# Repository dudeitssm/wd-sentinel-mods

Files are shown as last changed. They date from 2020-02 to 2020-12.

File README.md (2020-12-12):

WD Sentinel NAS related mods and custom PCBs
---

Contains custom PCBs, mods, etc, relating to the WD Sentinel DX4000 NAS.

How to get started?

1. Download the KiCAD archives (zip files)
2. Unarchive the zips
3. Use OSHPark or any fabhouse to print out the ".kicad_pcb" PCBs

Shoot me an email or open an issue if you have questions: moltensolderlabs AT pm.me

Everything licensed as CC0. Do whatever you want with these files.

Enjoy! Other projects are available on my site: moltensolderlabs.com

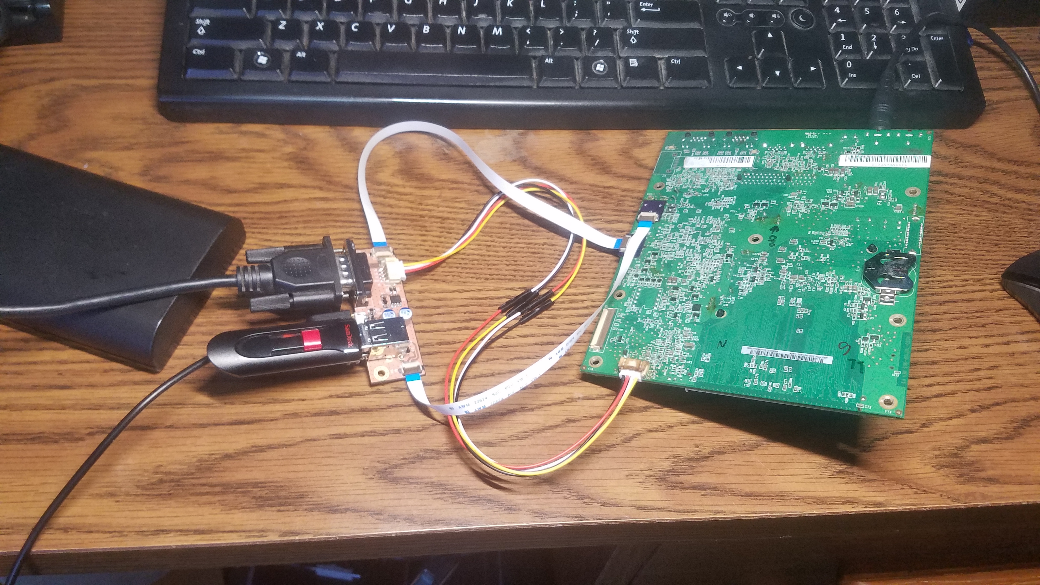
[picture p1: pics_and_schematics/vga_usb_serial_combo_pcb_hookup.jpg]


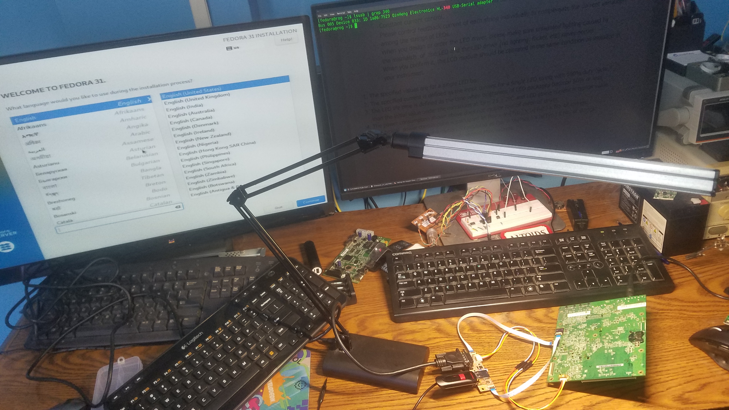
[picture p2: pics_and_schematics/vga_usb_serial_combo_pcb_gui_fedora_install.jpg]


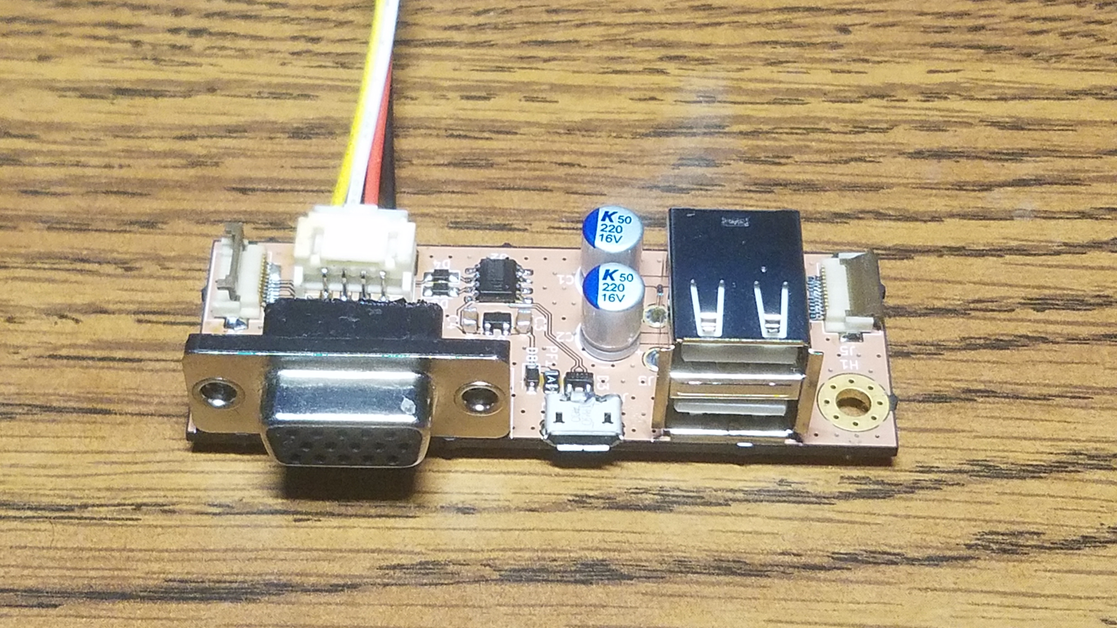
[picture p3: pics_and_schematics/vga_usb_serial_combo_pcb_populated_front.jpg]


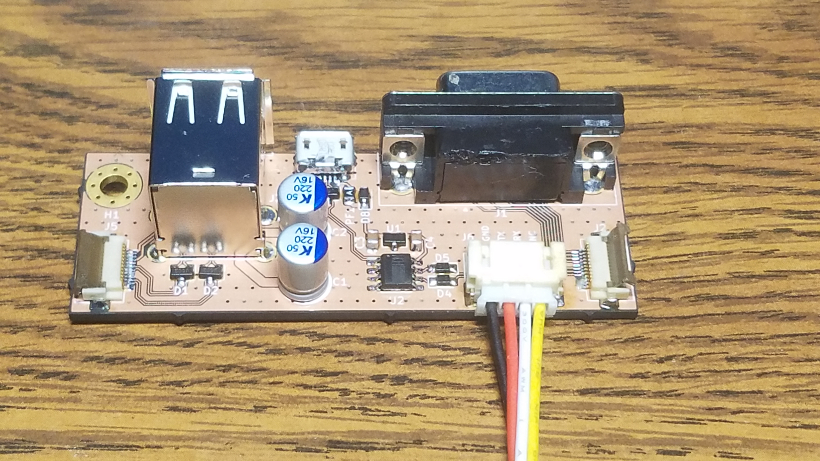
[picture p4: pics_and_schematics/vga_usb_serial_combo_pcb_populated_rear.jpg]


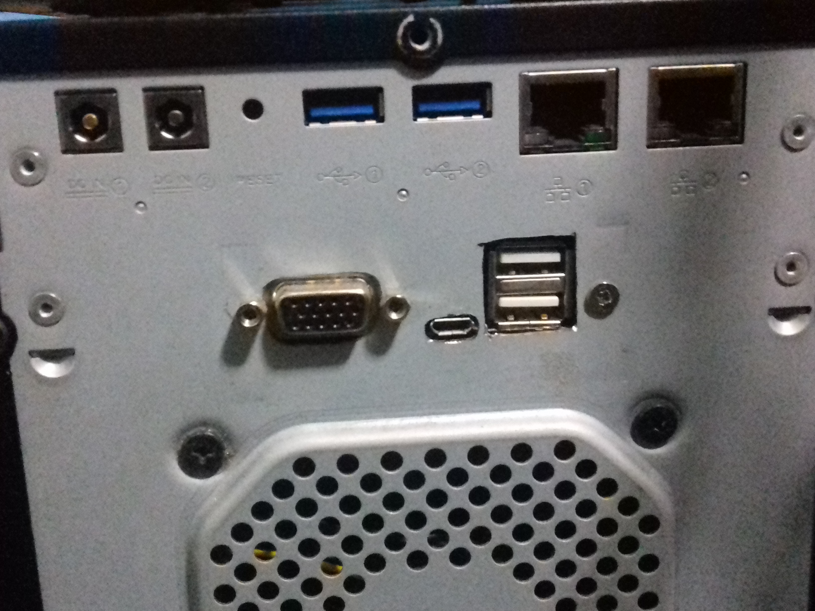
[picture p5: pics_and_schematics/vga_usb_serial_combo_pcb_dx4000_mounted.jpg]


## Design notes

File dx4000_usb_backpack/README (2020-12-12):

* This backpack is meant to be soldered onto the J15 header, a dual-USB header.
--> very lightly coat the pads with solder paste or solder, then use a hot air gun to solder.
--> a 12 pin FFC cable plugs into the combo PCB's USB header.
--> WARNING: you MUST use the same-side-up facing FFC cable, or you can short the USB.

* Note that F1 and F3 next to the J15 header are unpopulated. USB will not work without these.
--> you should solder 1 to 1.5A polyfuses; size, SMD 1210, 3.2mm x 2.5mm.

===

If ya liked this project, or have an improvement in mind, send me an email at moltensolderlabs AT pm.me

Cherish your little Sentinel! I love mine <3

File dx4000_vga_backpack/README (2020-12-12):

* This backpack is meant to be soldered onto the J3 header, a VGA header.
--> very lightly coat the pads with solder paste or solder, then use a hot air gun to solder.
--> a 12 pin FFC cable plugs into the combo PCB's VGA header.
--> WARNING: you MUST use the same-side-up facing FFC cable, or you can short the VGA.

===

If ya liked this project, or have an improvement in mind, send me an email at moltensolderlabs AT pm.me

Cherish your little Sentinel! I love mine <3

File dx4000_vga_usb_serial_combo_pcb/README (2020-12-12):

* This is a combo PCB that provides serial console, VGA, and dual USB2.0 support to the WD Sentinel DX4000.
--> a 12 pin FFC cable plugs into the USB backpack PCB.
--> a 12 pin FFC cable plugs into the VGA packpack PCB.
--> a 4 pin JST cable plugs into the serial port, located at the front of the DX4000 motherboard.
--> WARNING: you MUST use the same-side-up facing FFC cable, or you can short the USB or VGA.

===

If ya liked this project, or have an improvement in mind, send me an email at moltensolderlabs AT pm.me

Cherish your little Sentinel! I love mine <3

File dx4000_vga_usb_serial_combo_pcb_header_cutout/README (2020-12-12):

1. Print out the PDF file with *scaling DISABLED*
2. See that horizontal line above the cutouts? Get a ruler and see it measures exactly, or very close (+/-1mm) to 7cm
3. Tape the cutout to your DX4000 where the Windows Server COA sticker is located.
4. Disconnect and take out the motherboard and all HDDs.
5. Use a center punch to make dents where holes will be drilled.
6. Use a dremel/drill/file/whatever to cut out slots for the VGA, USB, and microUSB ports, and drill holes where indicated.
7. Solder and install the VGA, serial, USB combo PCB.
8. ??
9. Profit. You now have a DX4200, basically.

===

If ya liked this project, or have an improvement in mind, send me an email at moltensolderlabs AT pm.me

Cherish your little Sentinel! I love mine <3

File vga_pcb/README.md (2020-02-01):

A very small, and therefore, very cheap VGA PCB for the Sentinel DX4000.

It needs a small daughterboard that has to be soldered, using hot air gun, onto the 12 pin VGA header on the Sentinel's motherboard.

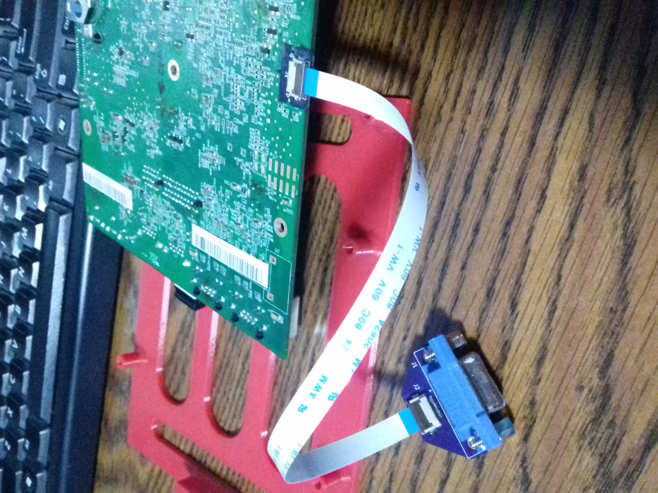
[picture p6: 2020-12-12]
pics_and_schematics/vga_backpack.jpg

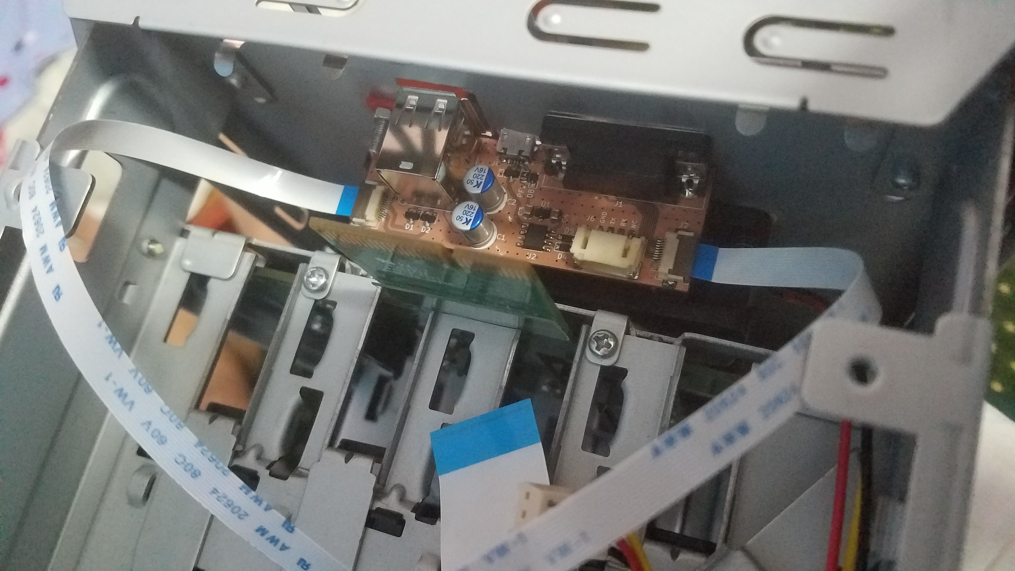
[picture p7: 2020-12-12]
pics_and_schematics/vga_usb_serial_combo_pcb_hookup_internal.jpg

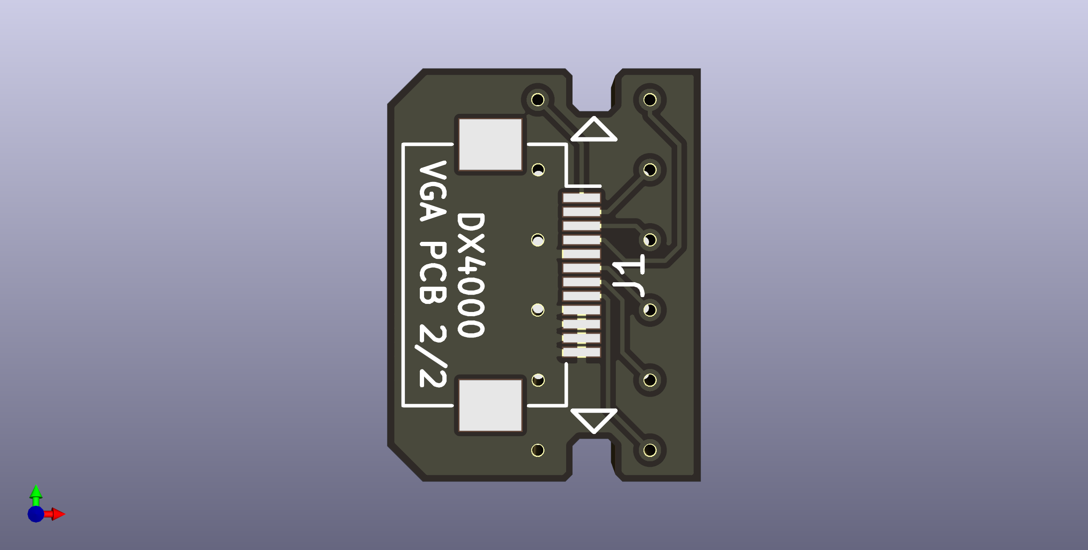
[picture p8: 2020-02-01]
vga_pcb/dx4000_vga_pcb_2_of_2.png

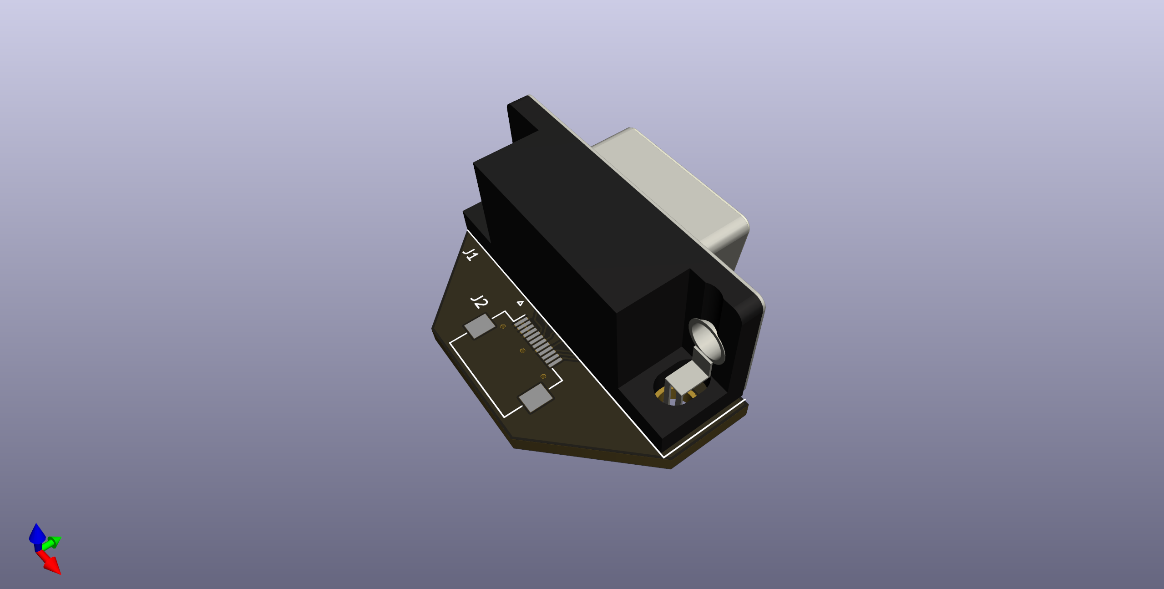
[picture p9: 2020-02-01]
vga_pcb/dx4000_vga_pcb_1_of_2.png

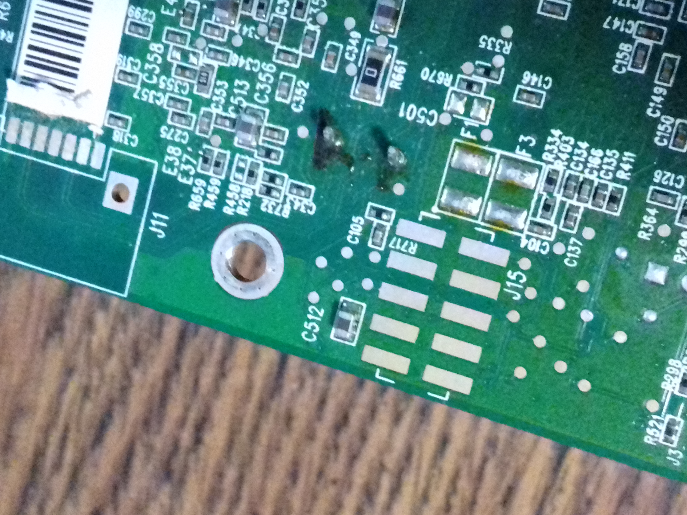
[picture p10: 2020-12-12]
dx4000_usb_backpack/j15_usb_header.jpg

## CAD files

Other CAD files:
dx4000_vga_usb_serial_combo_pcb_header_cutout/dx4000_vga_usb_serial_combo_pcb_cutout.FCStd

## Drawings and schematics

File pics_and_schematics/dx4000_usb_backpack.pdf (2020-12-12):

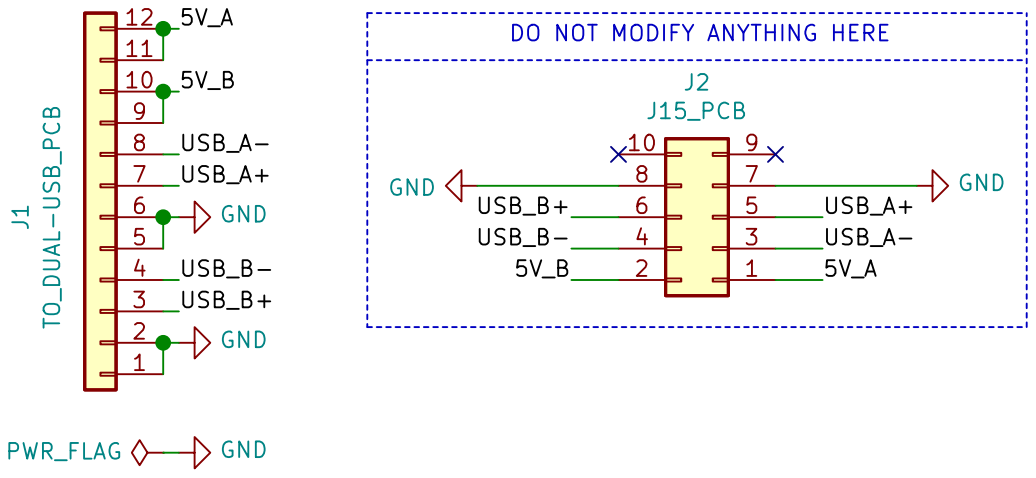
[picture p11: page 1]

File: dx4000_usb_backpack.sch Sheet: / Molten Solder Labs

Id: 1/1 Title: DX4000 USB Backpack

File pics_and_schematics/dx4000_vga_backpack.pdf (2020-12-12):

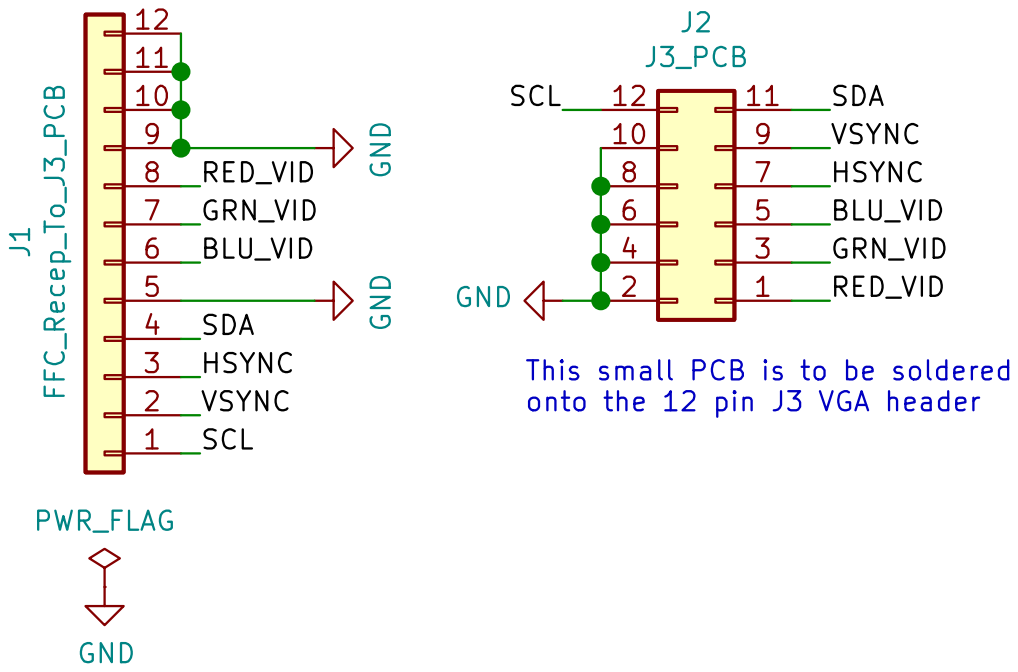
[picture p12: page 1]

This small PCB is to be soldered
onto the 12 pin J3 VGA header

File: dx4000_vga_backpack.sch Sheet: / Molten Solder Labs PWR_FLAG

Id: 1/1 Title: WD DX4000 VGA Backpack

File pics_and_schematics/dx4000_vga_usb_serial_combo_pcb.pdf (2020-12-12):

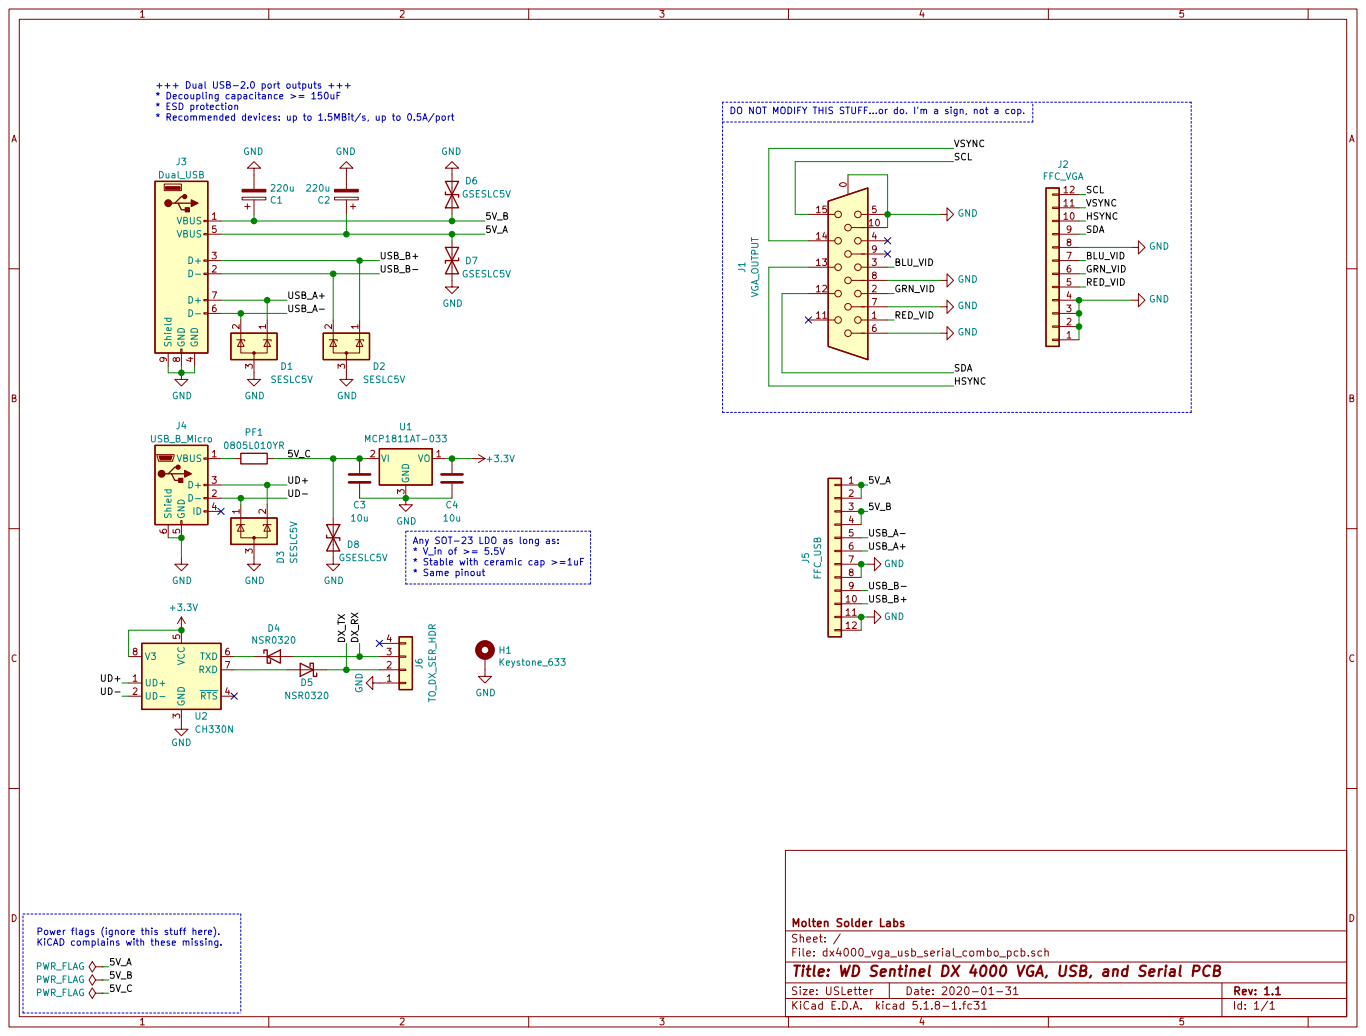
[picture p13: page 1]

+++ Dual USB-2.0 port outputs +++
* Decoupling capacitance >= 150uF
* ESD protection
* Recommended devices: up to 1.5MBit/s, up to 0.5A/port

DO NOT MODIFY THIS STUFF...or do. I'm a sign, not a cop.

Any SOT-23 LDO as long as: * V_in of >= 5.5V

* Stable with ceramic cap >=1uF
* Same pinout

Power flags (ignore this stuff here).
KiCAD complains with these missing.

File: dx4000_vga_usb_serial_combo_pcb.sch Sheet: / Molten Solder Labs

Id: 1/1 Title: WD Sentinel DX 4000 VGA, USB, and Serial PCB

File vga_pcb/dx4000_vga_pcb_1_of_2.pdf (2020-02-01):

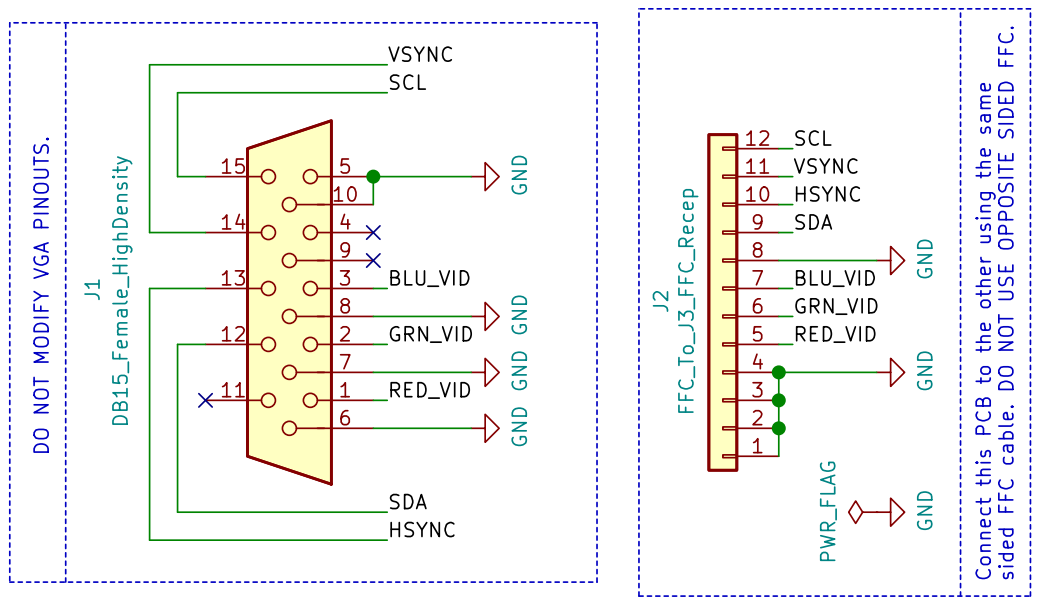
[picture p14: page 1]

File: dx4000_vga_pcb_1_of_2.sch Sheet: / SM, Molten Solder Labs PCB 1 of 2 1

Id: 1/1 Title: WD DX4000 VGA PCB

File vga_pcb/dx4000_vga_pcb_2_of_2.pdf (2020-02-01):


This small PCB is to be soldered
onto the 12 pin J3 VGA header

File: dx4000_vga_pcb_2_of_2.sch Sheet: / Molten Solder Labs PCB 2 of 2 PWR_FLAG

Id: 1/1 Title: WD DX4000 VGA PCB

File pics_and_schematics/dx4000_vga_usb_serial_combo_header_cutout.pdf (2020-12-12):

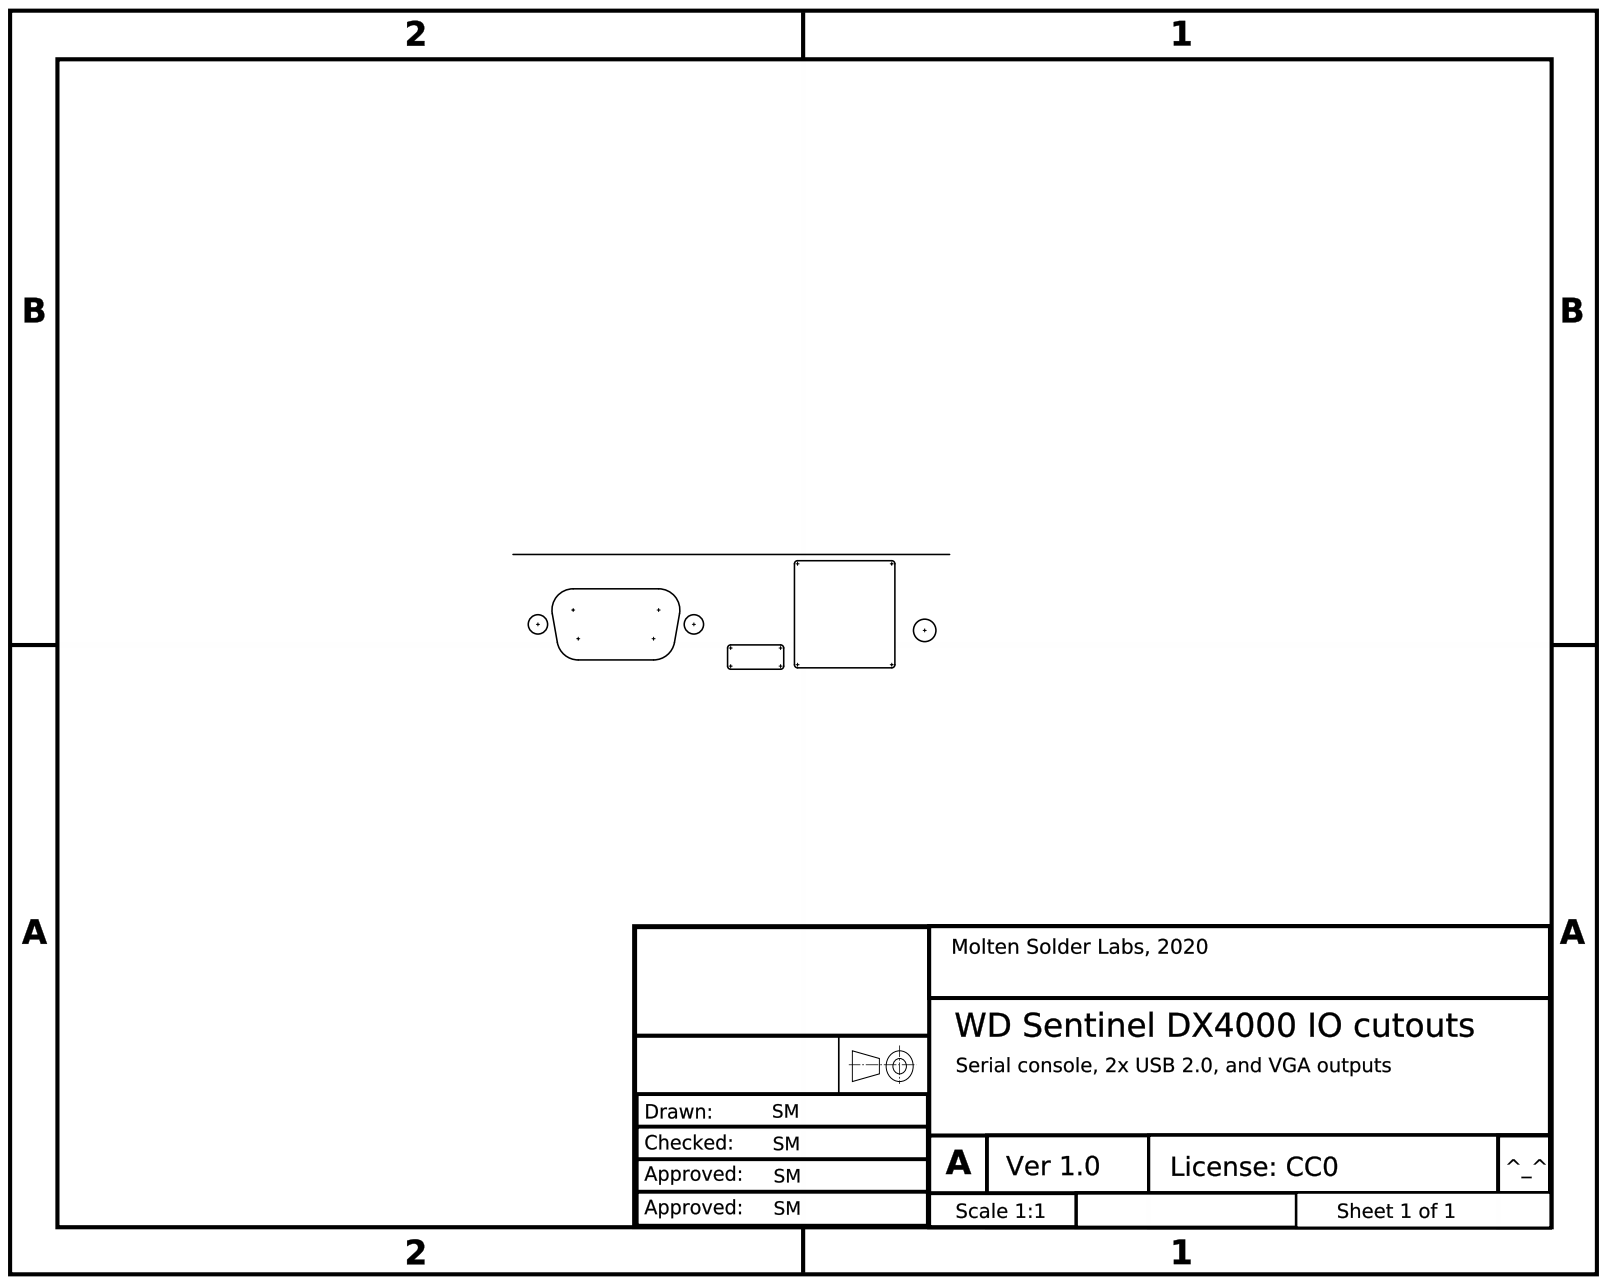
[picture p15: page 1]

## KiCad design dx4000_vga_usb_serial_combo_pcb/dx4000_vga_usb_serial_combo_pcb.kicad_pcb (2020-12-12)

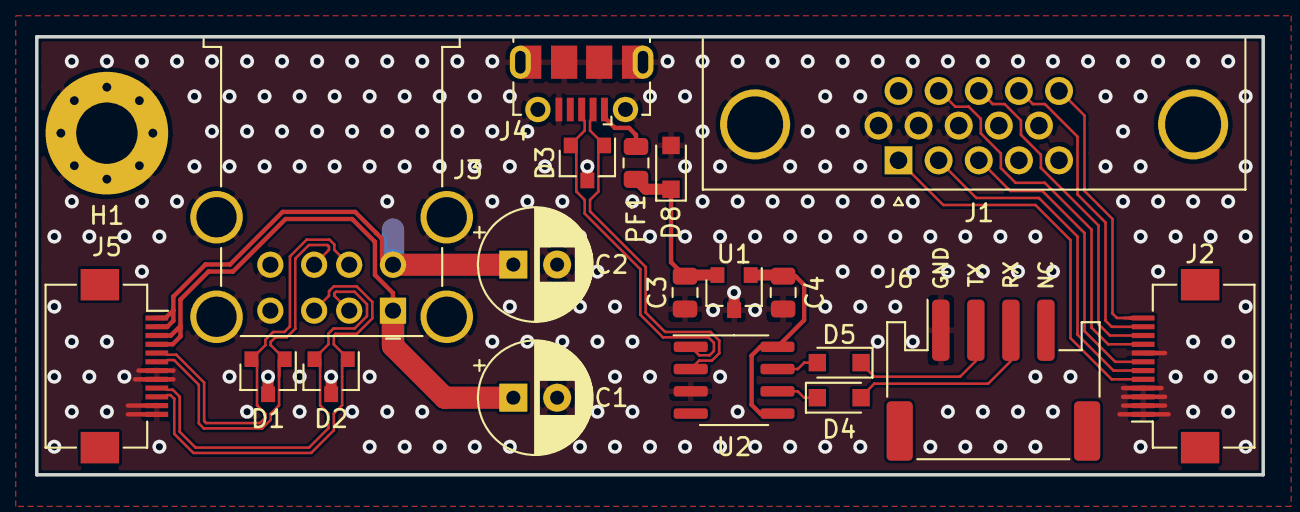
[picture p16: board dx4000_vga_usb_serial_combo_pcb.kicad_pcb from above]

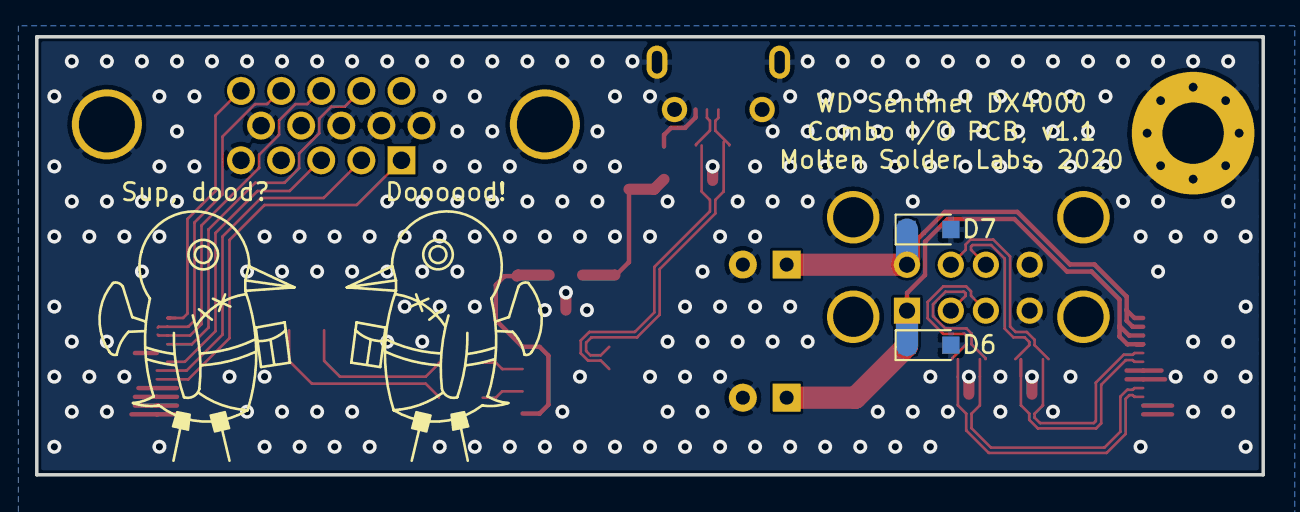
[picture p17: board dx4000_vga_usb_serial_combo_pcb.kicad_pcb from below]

Board: 2 copper layers, 70.0 x 25.0 mm, 22 parts (2 on the bottom side), 23 nets.

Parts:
C1, C2: 220u; CP_Radial_D6.3mm_P2.50mm
C3, C4: 10u; C_0805_2012Metric
D1, D2, D3: SESLC5V; SOT-23
D4, D5: NSR0320; D_SOD-323_HandSoldering
D6, D7, D8: GSESLC5V; D_SOD-323_HandSoldering
H1: Keystone_633; MountingHole_3.5mm_Pad_Via
J1: VGA_OUTPUT; DSUB-15-HD_Female_Horizontal_P2.29x1.98mm_EdgePinOffset3.03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
J2: FFC_VGA; Hirose_FH12-12S-0.5SH_1x12-1MP_P0.50mm_Horizontal
J3: Dual_USB; USB_A_Wuerth_61400826021_Horizontal_Stacked
J4: USB_B_Micro; USB_Micro-B_Molex-105017-0001
J5: FFC_USB; Hirose_FH12-12S-0.5SH_1x12-1MP_P0.50mm_Horizontal
J6: TO_DX_SER_HDR; JST_PH_S4B-PH-SM4-TB_1x04-1MP_P2.00mm_Horizontal
PF1: 0805L010YR; R_0805_2012Metric
U1: MCP1811AT-033; SOT-23
U2: CH330N; SOIC-8_3.9x4.9mm_P1.27mm

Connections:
+3V3: C4.1, U1.1, U2.5, U2.8
/5V_A: C2.1, D7.1, J3.5, J5.1, J5.2
/5V_B: C1.1, D6.1, J3.1, J5.3, J5.4
/5V_C: C3.1, D8.1, PF1.1, U1.2
/BLU_VID: J1.3, J2.7
/DX_RX: D4.2, J6.3
/DX_TX: D5.1, J6.2
/GRN_VID: J1.2, J2.6
/HSYNC: J1.13, J2.10
/RED_VID: J1.1, J2.5
/SCL: J1.15, J2.12
/SDA: J1.12, J2.9
/UD+: D3.2, J4.3, U2.1
/UD-: D3.1, J4.2, U2.2
/USB_A+: D1.1, J3.7, J5.6
/USB_A-: D1.2, J3.6, J5.5
/USB_B+: D2.1, J3.3, J5.10
/USB_B-: D2.2, J3.2, J5.9
/VSYNC: J1.14, J2.11
GND: C1.2, C2.2, C3.2, C4.2, D1.3, D2.3, D3.3, D6.2, D7.2, D8.2, H1.1, J1.0, J1.5, J1.6, J1.7, J1.8, J1.10, J2.1, J2.2, J2.3, J2.4, J2.8, J3.4, J3.8, J3.9, J4.5, J4.6, J5.7, J5.8, J5.11, J5.12, J6.1, U1.3, U2.3
unnamed: D4.1, U2.6
unnamed: D5.2, U2.7
unnamed: J4.1, PF1.2
